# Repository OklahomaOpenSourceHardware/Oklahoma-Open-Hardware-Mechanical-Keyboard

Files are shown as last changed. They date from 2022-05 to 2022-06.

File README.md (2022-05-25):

# Oklahoma-Open-Hardware-Mechanical-Keyboard
Oklahoma themed open source hardware licensed keyboard from the Oklahoma community

## Layout

http://www.keyboard-layout-editor.com/#/gists/58d102278691380e818329089bf505ac

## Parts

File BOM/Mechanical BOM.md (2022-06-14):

| Version  | Reference  | Quantity  | Description  | Link  |
|---|---|---|---|---|
| Proto | S1 | 8 | Phillips Flat Head Screws: M3 x 0.5 mm Thread, 14 mm Long | https://www.mcmaster.com/91420A124/  |
| Proto | T1 | 4 | Tapered Heat-Set Inserts for Plastic Brass, M3 x 0.50 mm Thread Size, 3.800 mm Installed Length | https://www.mcmaster.com/94180A331/ |
| Proto | A1 | 1 | 5.4mm Acrylic (Open cut file) | https://sendcutsend.com/materials/acrylic/ |
| Proto | A2 | 1 | 4.5mm Acrylic (Close cut file) | https://sendcutsend.com/materials/acrylic/ |
| Proto | F1 | 1 | 1.6mm FR4 (Top Plate) | (link to gerber file) |
| Proto | F2 | 1 | 1.6mm FR4 (Keyboard PCB) | (link to gerber file) |
| Proto | F3 | 1 | 1.6mm FR4 (Bottom Plate) | (link to gerber file) |
| Proto | W1 | 1 | 9mm  Wedge Wood/Plastic | (link to 3D model file) |
| Proto | W2 | 1 | 8mm  Switch Cover Wood/Plastic | (link to 3D model file) |
| Proto | W3 | 1 | ~3mm  PCB Spacer TPU/Foam Plastic | (link to 3D model file) |

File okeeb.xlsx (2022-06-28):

Value | Reference(s) | Footprint
0.1u | C1, C2, C3, C4 | Capacitor_SMD:C_0805_2012Metric_Pad1.18x1.45mm_HandSolder
4.7u | C5 | Capacitor_SMD:C_0805_2012Metric_Pad1.18x1.45mm_HandSolder
22p | C6, C7 | Capacitor_SMD:C_0805_2012Metric_Pad1.18x1.45mm_HandSolder
1u | C8 | Capacitor_SMD:C_0805_2012Metric_Pad1.18x1.45mm_HandSolder
D | D0, D1, D2, D3, D4, D5, D6, D7, D8, D9, D10, D11, D12, D13, D14, D16, D17, D18, D19, D20, D21, D22, D23, D24, D25, D26, D27, D28, D29, D30, D31, D32, D33, D34, D35, D36, D37, D38, D39, D40, D41, D42, D43, D44, D45, D46, D47, D48, D49, D50, D51, D52, D53, D54, D55, D56, D57, D58, D59, D60, D61, D62, D63 | Diode_SMD:D_0805_2012Metric_Pad1.15x1.40mm_HandSolder
w_2 stabilizer | DRA1, DRA2, DRA5 | Mounting_Keyboard_Stabilizer:Stabilizer_Cherry_MX_2.00u
w_3 stabilizer | DRA3, DRA4 | Mounting_Keyboard_Stabilizer:Stabilizer_Cherry_MX_3.00u
MountingHole | H1, H2, H3, H4 | MountingHole:MountingHole_3.2mm_M3_DIN965
USB_B_Micro | J1 | Connector_USB:USB_Micro-B_Wuerth_629105150521_CircularHoles
Conn_02x03_Odd_Even | J2 | Connector_PinHeader_2.54mm:PinHeader_2x03_P2.54mm_Vertical
KEYSW | K0, K1, K2, K3, K4, K5, K6, K7, K8, K9, K10, K11, K12, K13, K14, K16, K17, K18, K19, K20, K21, K22, K23, K24, K25, K26, K27, K28, K29, K30, K31, K32, K33, K34, K35, K36, K37, K38, K39, K40, K41, K42, K43, K44, K45, K46, K47, K48, K49, K50, K51, K52, K53, K54, K55, K56, K57, K58, K59, K60, K61, K62, K63 | keyswitches:Kailh_socket_MX_p1ref
10k | R1, R4 | Resistor_SMD:R_0805_2012Metric_Pad1.20x1.40mm_HandSolder
22R | R2, R3 | Resistor_SMD:R_0805_2012Metric_Pad1.20x1.40mm_HandSolder
Reset_SW | SW1 | Button_Switch_SMD:SW_Push_1P1T_NO_6x6mm_H9.5mm
ATmega32U4-A | U1 | Package_QFP:TQFP-44_10x10mm_P0.8mm
Crystal | Y1 | Crystal:Crystal_SMD_5032-2Pin_5.0x3.2mm_HandSoldering

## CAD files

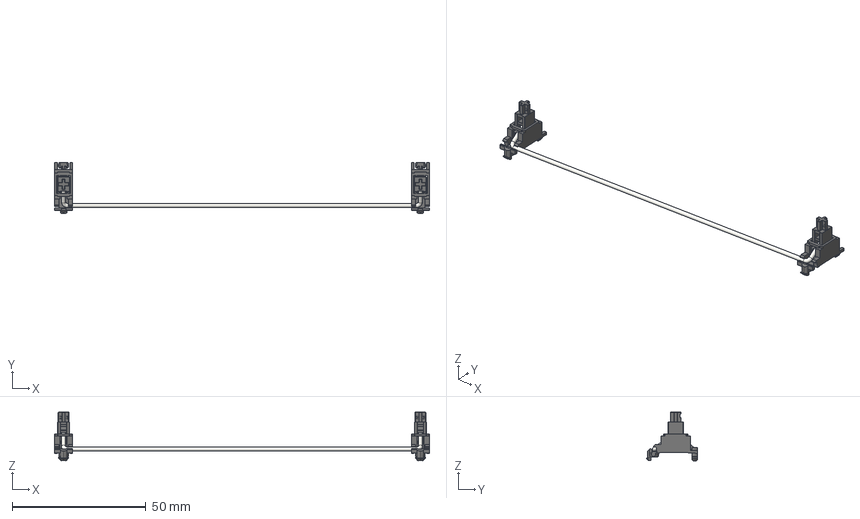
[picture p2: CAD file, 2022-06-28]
keyswitch-kicad-library-main/source_3d/Mounting_Keyboard_Stabilizer/Stabilizer_Cherry_MX_8u.FCStd
140.1 x 19.2 x 18.3 mm
Bar
Stabilizer_Key_
Stabilizer_Base_
Stabilizer_Key
Stabilizer_Base

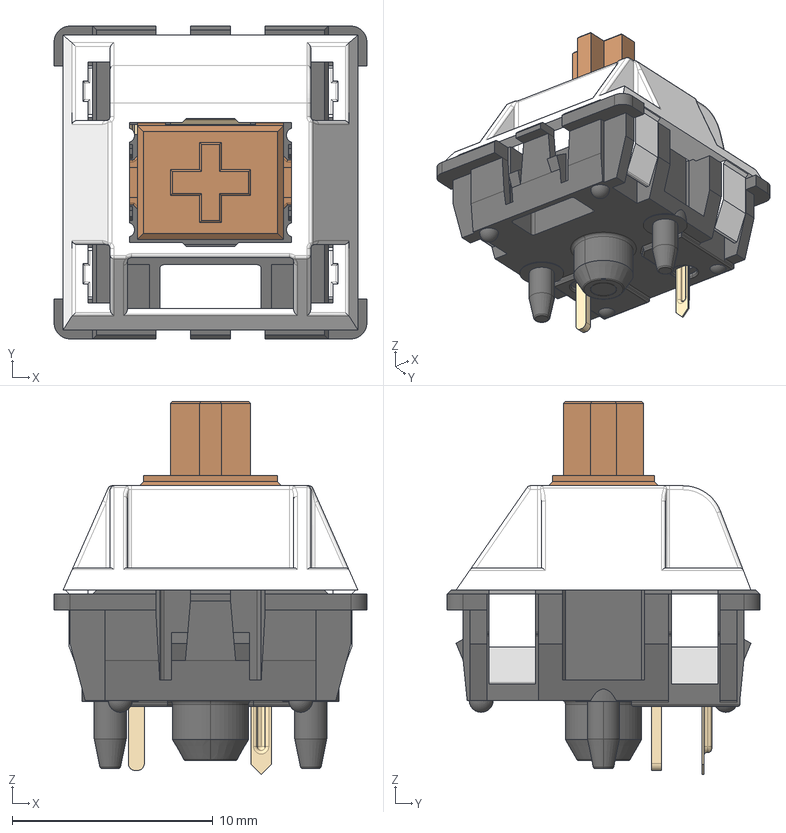
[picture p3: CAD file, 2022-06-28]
keyswitch-kicad-library-main/source_3d/Switch_Keyboard_Cherry_MX/SW_Cherry_MX_PCB.FCStd
15.6 x 15.6 x 18.6 mm
Lower_Housing
Upper_Housing
Stem
Pin_1
Pin_2
Spring
Clicker

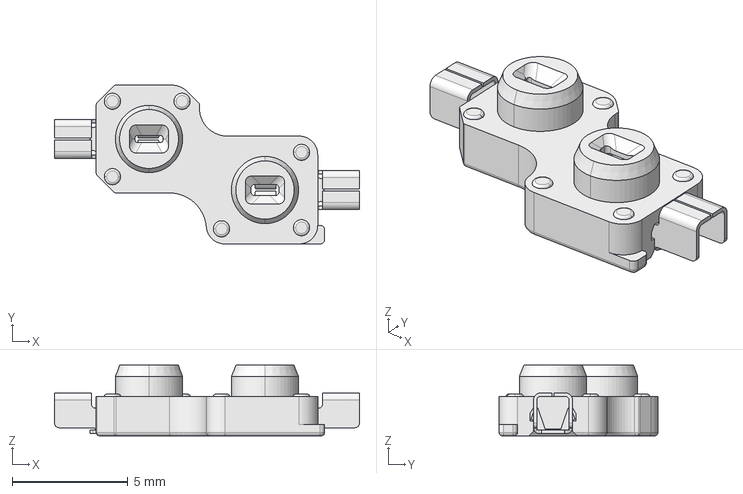
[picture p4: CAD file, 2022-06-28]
keyswitch-kicad-library-main/source_3d/Switch_Keyboard_Kailh/SW_Hotswap_Kailh_Choc_v1.FCStd
13.2 x 6.85 x 3.05 mm

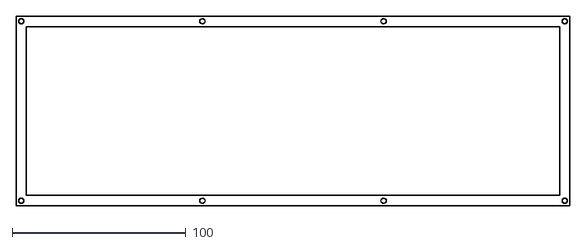
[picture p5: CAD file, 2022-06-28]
Mechanical/1d330ba3ae6bdd7f7d86c17163a86d3b664da0f7_closed.dxf
318.8 x 109.2

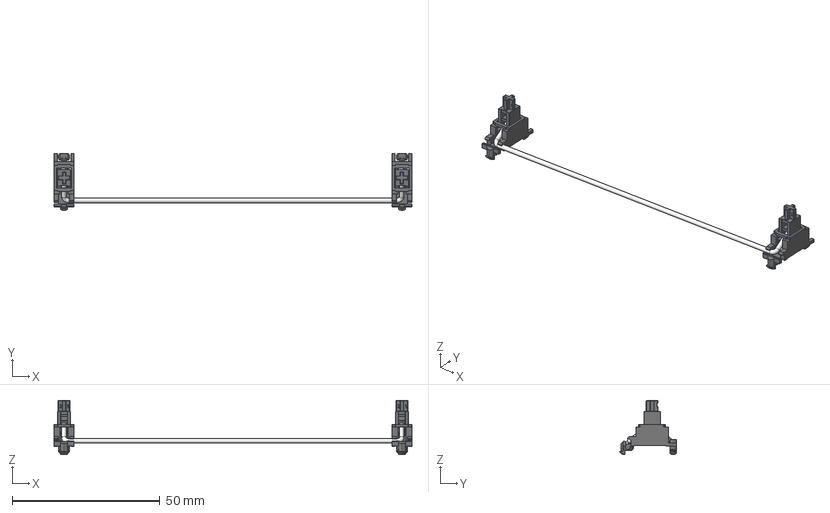
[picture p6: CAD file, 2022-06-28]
keyswitch-kicad-library-main/source_3d/Mounting_Keyboard_Stabilizer/Stabilizer_Cherry_MX_7u.FCStd
121.1 x 19.2 x 18.3 mm
Bar
Stabilizer_Key_
Stabilizer_Base_
Stabilizer_Key
Stabilizer_Base

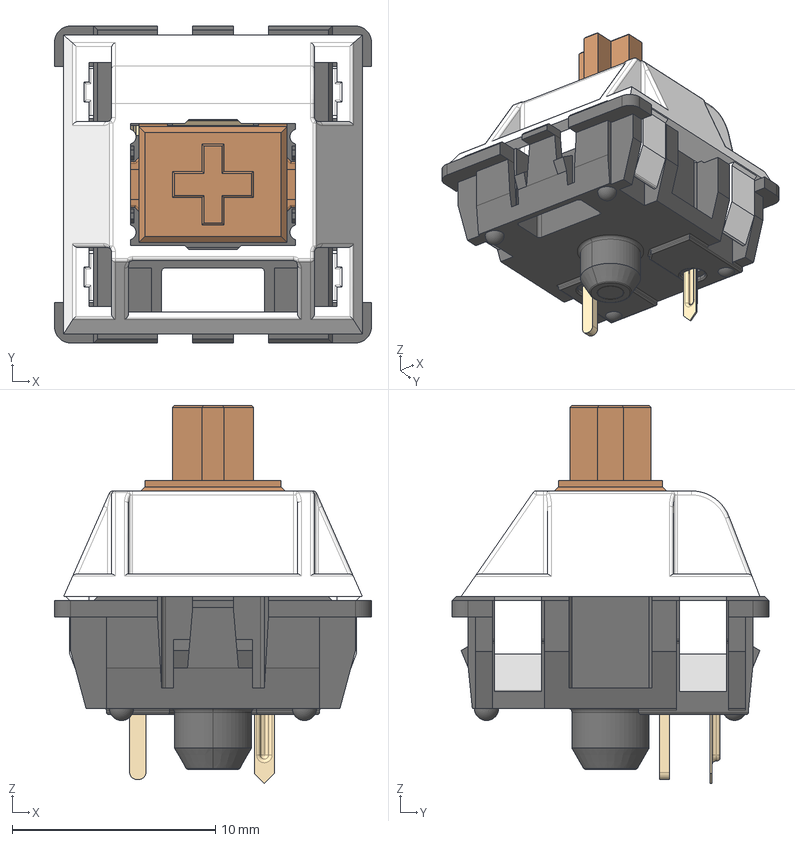
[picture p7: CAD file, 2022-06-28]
keyswitch-kicad-library-main/source_3d/Switch_Keyboard_Cherry_MX/SW_Cherry_MX_Plate.FCStd
15.6 x 15.6 x 18.6 mm
Lower_Housing
Upper_Housing
Stem
Pin_1
Pin_2
Spring
Clicker

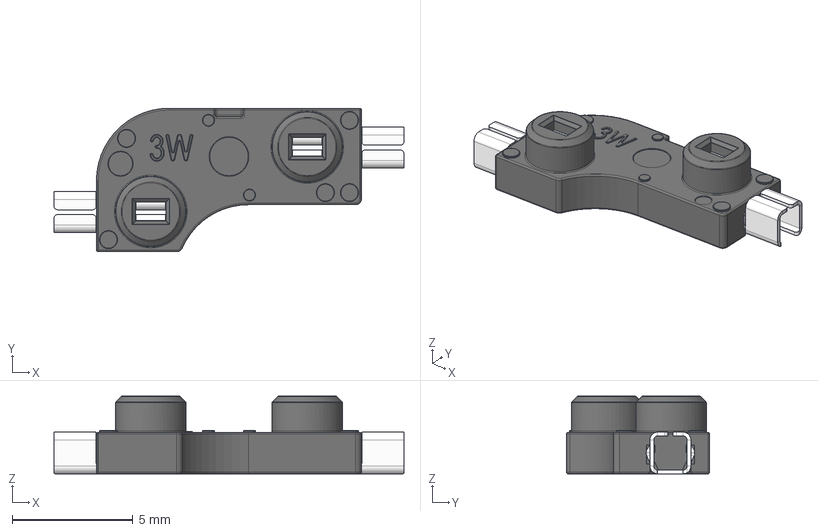
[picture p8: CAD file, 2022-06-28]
keyswitch-kicad-library-main/source_3d/Switch_Keyboard_Kailh/SW_Hotswap_Kailh.FCStd
14.5 x 5.95 x 3.22 mm
Pin_1
Pin_2
Plastic

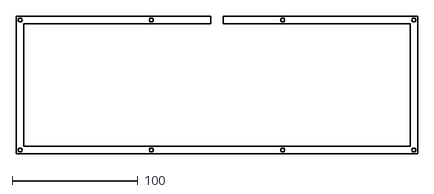
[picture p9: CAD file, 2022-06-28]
Mechanical/1d330ba3ae6bdd7f7d86c17163a86d3b664da0f7_open.dxf
318.8 x 109.2

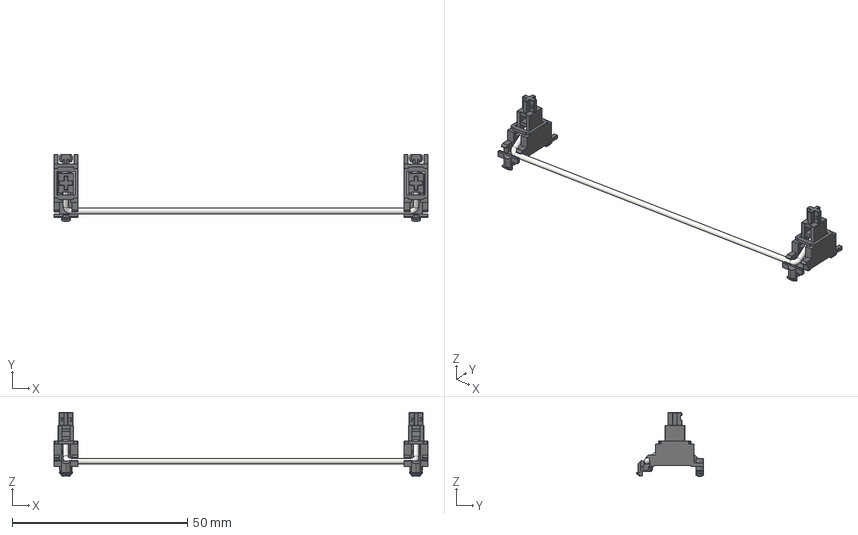
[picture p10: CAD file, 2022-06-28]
keyswitch-kicad-library-main/source_3d/Mounting_Keyboard_Stabilizer/Stabilizer_Cherry_MX_6.25u.FCStd
106.8 x 19.2 x 18.3 mm
Bar
Stabilizer_Key_
Stabilizer_Base_
Stabilizer_Key
Stabilizer_Base

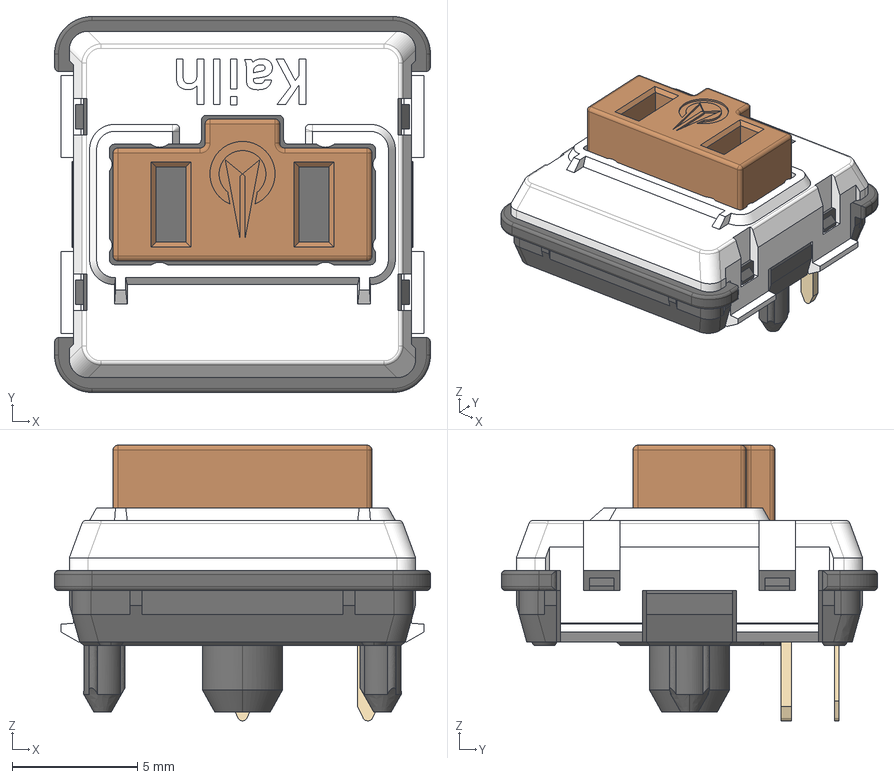
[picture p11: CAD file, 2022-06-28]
keyswitch-kicad-library-main/source_3d/Switch_Keyboard_Kailh/SW_Kailh_Choc_V1.FCStd
15.0 x 15.0 x 11.0 mm
Upper_Housing
Lower_Housing
Stem
Pin_2
Pin_1

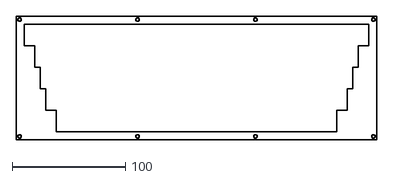
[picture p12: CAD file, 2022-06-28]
Mechanical/1d330ba3ae6bdd7f7d86c17163a86d3b664da0f7_top.dxf
318.8 x 109.2

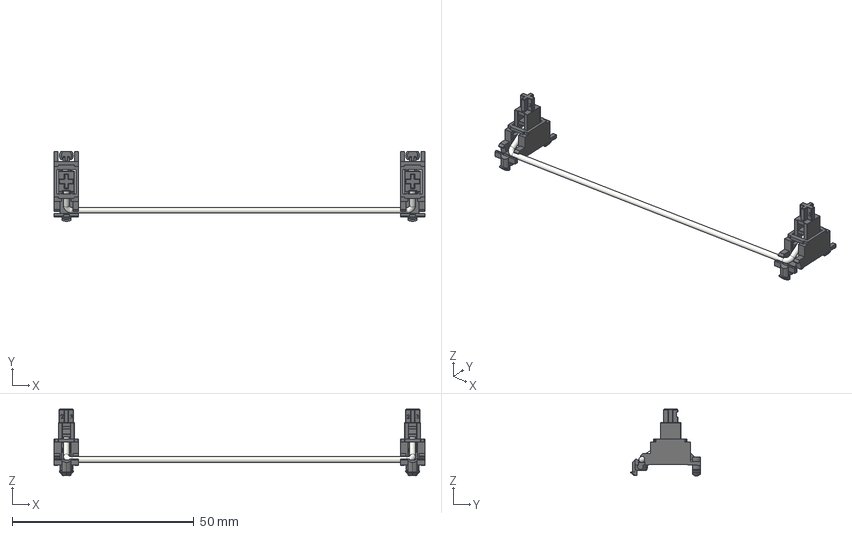
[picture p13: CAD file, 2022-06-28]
keyswitch-kicad-library-main/source_3d/Mounting_Keyboard_Stabilizer/Stabilizer_Cherry_MX_6u.FCStd
102.1 x 19.2 x 18.3 mm
Bar
Stabilizer_Key_
Stabilizer_Base_
Stabilizer_Key
Stabilizer_Base

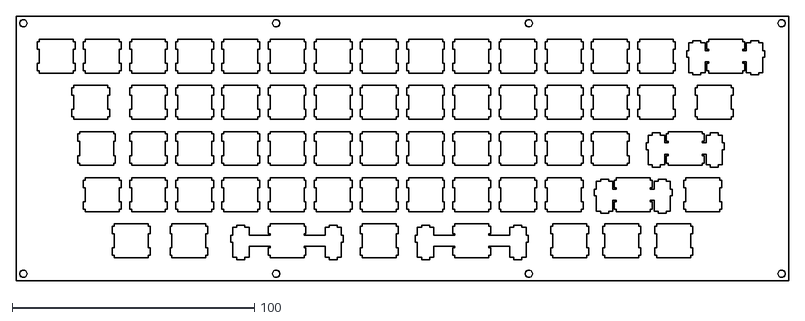
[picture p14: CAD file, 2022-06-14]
Mechanical/1d330ba3ae6bdd7f7d86c17163a86d3b664da0f7_switch.dxf
318.8 x 109.2

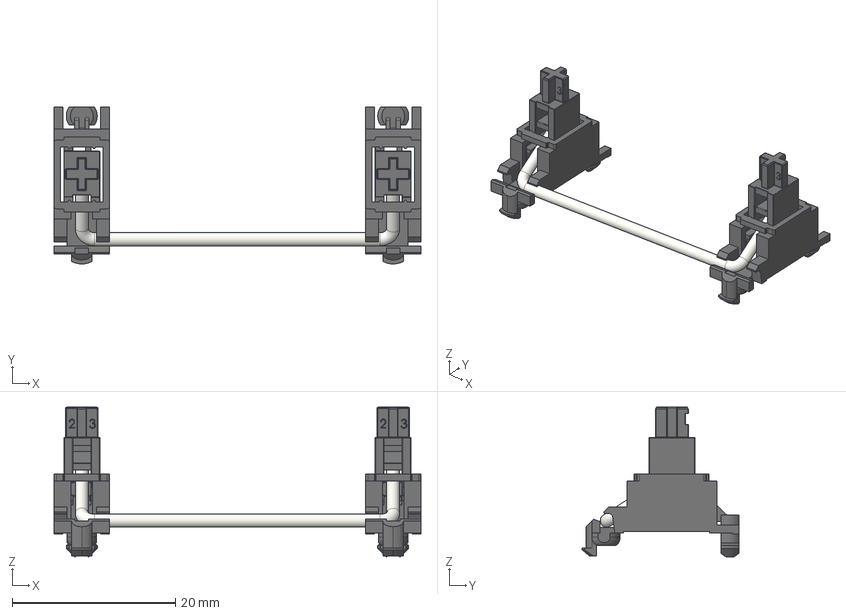
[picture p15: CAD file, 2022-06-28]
keyswitch-kicad-library-main/source_3d/Mounting_Keyboard_Stabilizer/Stabilizer_Cherry_MX_3u.FCStd
44.9 x 19.2 x 18.3 mm
Bar
Stabilizer_Key_
Stabilizer_Base_
Stabilizer_Key
Stabilizer_Base

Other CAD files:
Mechanical/1d330ba3ae6bdd7f7d86c17163a86d3b664da0f7_bottom.dxf
keyswitch-kicad-library-main/source_3d/Mounting_Keyboard_Stabilizer/Stabilizer_Cherry_MX_2u.FCStd

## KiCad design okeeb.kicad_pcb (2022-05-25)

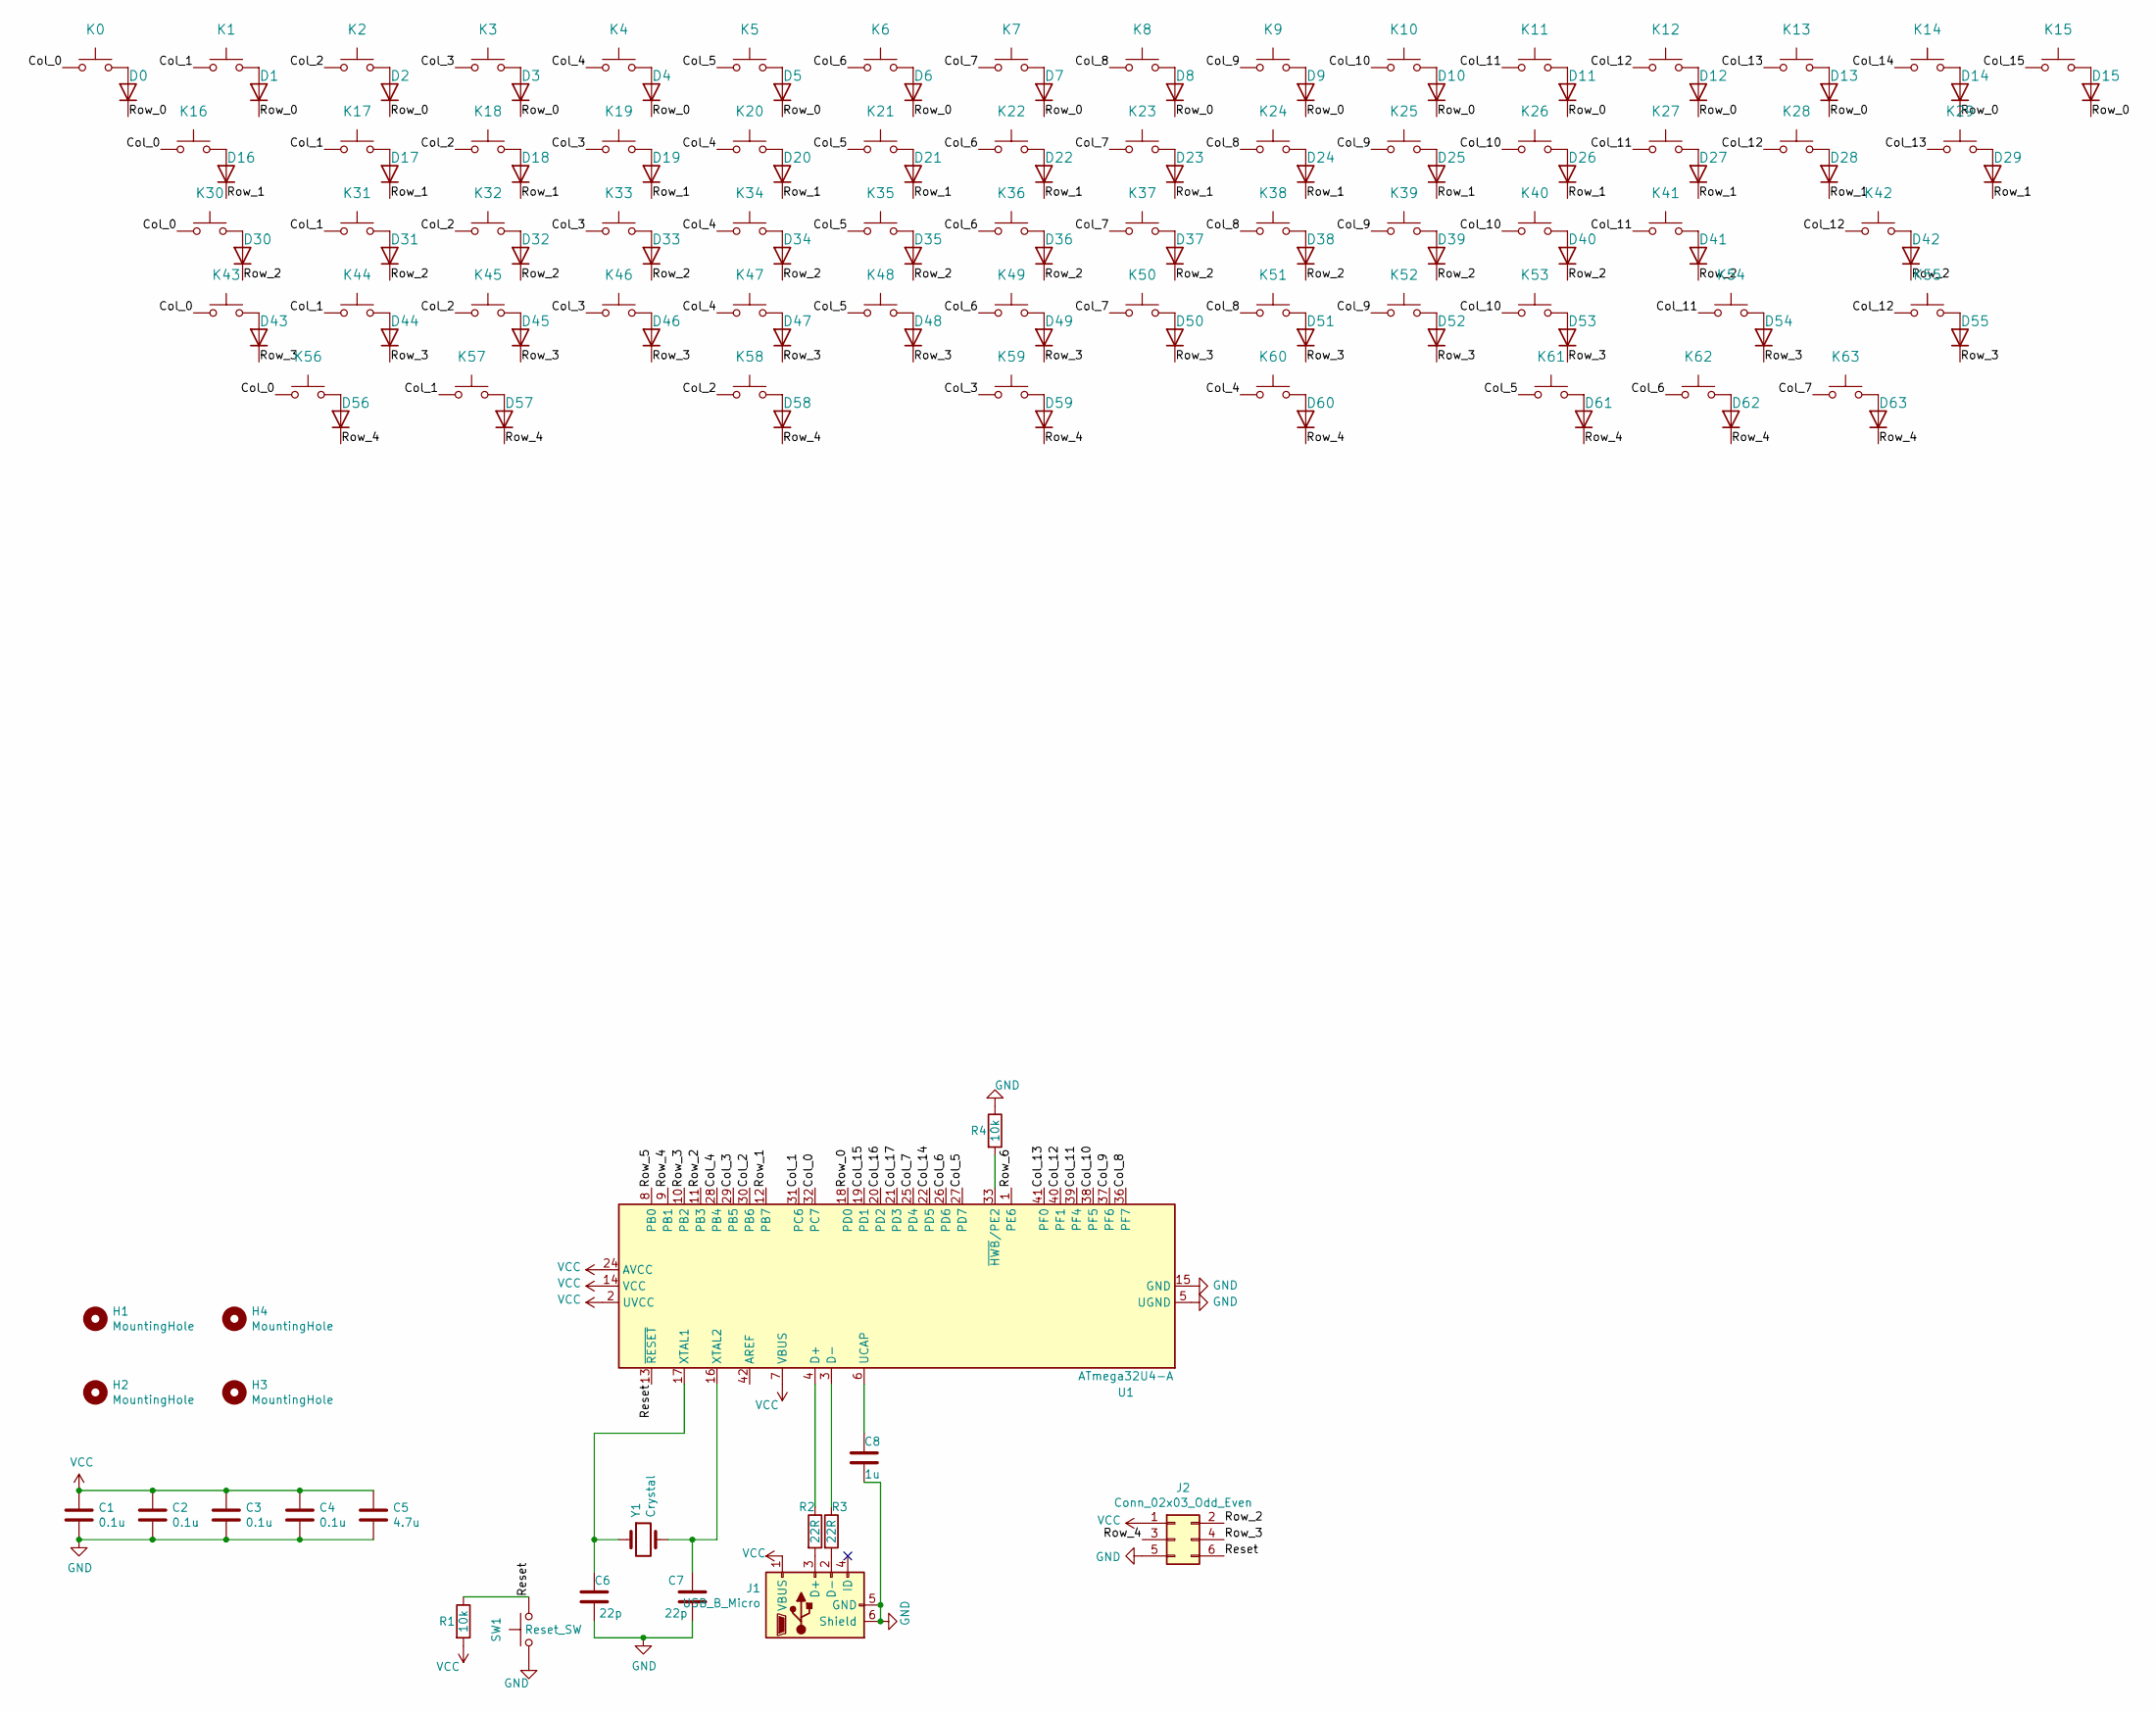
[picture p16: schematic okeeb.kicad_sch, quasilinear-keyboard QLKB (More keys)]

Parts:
C1, C2, C3, C4: 0.1u; C_0805_2012Metric_Pad1.15x1.40mm_HandSolder
C5: 4.7u; C_0805_2012Metric_Pad1.15x1.40mm_HandSolder
C6, C7: 22p; C_0805_2012Metric_Pad1.15x1.40mm_HandSolder
C8: 1u; C_0805_2012Metric_Pad1.15x1.40mm_HandSolder
D0, D1, D2, D3, D4, D5, D6, D7, D8, D9, D10, D11, D12, D13, D14, D15, D16, D17, D18, D19, D20, D21, D22, D23, D24, D25, D26, D27, D28, D29, D30, D31, D32, D33, D34, D35, D36, D37, D38, D39, D40, D41, D42, D43, D44, D45, D46, D47, D48, D49, D50, D51, D52, D53, D54, D55, D56, D57, D58, D59, D60, D61, D62, D63: D; D_0805_2012Metric_Pad1.15x1.40mm_HandSolder
H1, H2, H3, H4: MountingHole; MountingHole_3.2mm_M3_DIN965
J1: USB_B_Micro; USB_Micro-B_Wuerth_629105150521_CircularHoles
J2: Conn_02x03_Odd_Even; PinHeader_2x03_P2.54mm_Vertical
K0, K1, K2, K3, K4, K5, K6, K7, K8, K9, K10, K11, K12, K13, K14, K15, K17, K18, K19, K20, K21, K22, K23, K24, K25, K26, K27, K28, K31, K32, K33, K34, K35, K36, K37, K38, K39, K40, K41, K43, K44, K45, K46, K47, K48, K49, K50, K51, K52, K53, K55, K59, K62: KEYSW; SW_Cherry_MX_1.00u_PCB
K16, K29: KEYSW; SW_Cherry_MX_1.50u_PCB
K30, K56, K57, K61, K63: KEYSW; SW_Cherry_MX_1.25u_PCB
K42: KEYSW; SW_Cherry_MX_2.25u_PCB
K54: KEYSW; SW_Cherry_MX_2.00u_PCB
K58, K60: KEYSW; SW_Cherry_MX_2.75u_PCB
R1, R4: 10k; R_0805_2012Metric_Pad1.15x1.40mm_HandSolder
R2, R3: 22R; R_0805_2012Metric_Pad1.15x1.40mm_HandSolder
SW1: Reset_SW; SW_Push_1P1T_NO_6x6mm_H9.5mm
U1: ATmega32U4-A; TQFP-44_10x10mm_P0.8mm
Y1: Crystal; Crystal_SMD_5032-2Pin_5.0x3.2mm_HandSoldering

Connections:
/Col_0: K0.1, K16.1, K30.1, K43.1, K56.1, U1.32 (PC7)
/Col_1: K1.1, K17.1, K31.1, K44.1, K57.1, U1.31 (PC6)
/Col_2: K2.1, K18.1, K32.1, K45.1, K58.1, U1.30 (PB6)
/Col_3: K3.1, K19.1, K33.1, K46.1, K59.1, U1.29 (PB5)
/Col_4: K4.1, K20.1, K34.1, K47.1, K60.1, U1.28 (PB4)
/Col_5: K5.1, K21.1, K35.1, K48.1, K61.1, U1.27 (PD7)
/Col_6: K6.1, K22.1, K36.1, K49.1, K62.1, U1.26 (PD6)
/Col_7: K7.1, K23.1, K37.1, K50.1, K63.1, U1.25 (PD4)
/Col_8: K8.1, K24.1, K38.1, K51.1, U1.36 (PF7)
/Col_9: K9.1, K25.1, K39.1, K52.1, U1.37 (PF6)
/Col_10: K10.1, K26.1, K40.1, K53.1, U1.38 (PF5)
/Col_11: K11.1, K27.1, K41.1, K54.1, U1.39 (PF4)
/Col_12: K12.1, K28.1, K42.1, K55.1, U1.40 (PF1)
/Col_13: K13.1, K29.1, U1.41 (PF0)
/Col_14: K14.1, U1.22 (PD5)
/Col_15: K15.1, U1.19 (PD1)
/Col_16: U1.20 (PD2)
/Col_17: U1.21 (PD3)
/Row_0: D0.1 (K), D1.1 (K), D2.1 (K), D3.1 (K), D4.1 (K), D5.1 (K), D6.1 (K), D7.1 (K), D8.1 (K), D9.1 (K), D10.1 (K), D11.1 (K), D12.1 (K), D13.1 (K), D14.1 (K), D15.1 (K), U1.18 (PD0)
/Row_1: D16.1 (K), D17.1 (K), D18.1 (K), D19.1 (K), D20.1 (K), D21.1 (K), D22.1 (K), D23.1 (K), D24.1 (K), D25.1 (K), D26.1 (K), D27.1 (K), D28.1 (K), D29.1 (K), U1.12 (PB7)
/Row_2: D30.1 (K), D31.1 (K), D32.1 (K), D33.1 (K), D34.1 (K), D35.1 (K), D36.1 (K), D37.1 (K), D38.1 (K), D39.1 (K), D40.1 (K), D41.1 (K), D42.1 (K), J2.2, U1.11 (PB3)
/Row_3: D43.1 (K), D44.1 (K), D45.1 (K), D46.1 (K), D47.1 (K), D48.1 (K), D49.1 (K), D50.1 (K), D51.1 (K), D52.1 (K), D53.1 (K), D54.1 (K), D55.1 (K), J2.4, U1.10 (PB2)
/Row_4: D56.1 (K), D57.1 (K), D58.1 (K), D59.1 (K), D60.1 (K), D61.1 (K), D62.1 (K), D63.1 (K), J2.3, U1.9 (PB1)
/Row_5: U1.8 (PB0)
/Row_6: U1.1 (PE6)
GND: C1.2, C2.2, C3.2, C4.2, C5.2, C6.2, C7.2, C8.2, J1.5 (GND), J1.6 (Shield), J2.5, R4.1, SW1.1, U1.5 (UGND), U1.15 (GND), U1.23 (GND), U1.35 (GND), U1.43 (GND)
unnamed: C6.1, U1.17 (XTAL1), Y1.1
unnamed: C7.1, U1.16 (XTAL2), Y1.2
unnamed: C8.1, U1.6 (UCAP)
unnamed: D0.2 (A), K0.2
unnamed: D1.2 (A), K1.2
unnamed: D2.2 (A), K2.2
unnamed: D3.2 (A), K3.2
unnamed: D4.2 (A), K4.2
unnamed: D5.2 (A), K5.2
unnamed: D6.2 (A), K6.2
unnamed: D7.2 (A), K7.2
unnamed: D8.2 (A), K8.2
unnamed: D9.2 (A), K9.2
unnamed: D10.2 (A), K10.2
unnamed: D11.2 (A), K11.2
unnamed: D12.2 (A), K12.2
unnamed: D13.2 (A), K13.2
unnamed: D14.2 (A), K14.2
unnamed: D15.2 (A), K15.2
unnamed: D16.2 (A), K16.2
unnamed: D17.2 (A), K17.2
unnamed: D18.2 (A), K18.2
unnamed: D19.2 (A), K19.2
unnamed: D20.2 (A), K20.2
unnamed: D21.2 (A), K21.2
unnamed: D22.2 (A), K22.2
unnamed: D23.2 (A), K23.2
unnamed: D24.2 (A), K24.2
unnamed: D25.2 (A), K25.2
unnamed: D26.2 (A), K26.2
unnamed: D27.2 (A), K27.2
unnamed: D28.2 (A), K28.2
unnamed: D29.2 (A), K29.2
unnamed: D30.2 (A), K30.2
unnamed: D31.2 (A), K31.2
unnamed: D32.2 (A), K32.2
unnamed: D33.2 (A), K33.2
unnamed: D34.2 (A), K34.2
unnamed: D35.2 (A), K35.2
unnamed: D36.2 (A), K36.2
unnamed: D37.2 (A), K37.2
unnamed: D38.2 (A), K38.2
unnamed: D39.2 (A), K39.2
unnamed: D40.2 (A), K40.2
unnamed: D41.2 (A), K41.2
unnamed: D42.2 (A), K42.2
unnamed: D43.2 (A), K43.2
unnamed: D44.2 (A), K44.2
unnamed: D45.2 (A), K45.2
unnamed: D46.2 (A), K46.2
unnamed: D47.2 (A), K47.2
unnamed: D48.2 (A), K48.2
unnamed: D49.2 (A), K49.2
unnamed: D50.2 (A), K50.2
unnamed: D51.2 (A), K51.2
unnamed: D52.2 (A), K52.2
unnamed: D53.2 (A), K53.2
unnamed: D54.2 (A), K54.2
unnamed: D55.2 (A), K55.2
unnamed: D56.2 (A), K56.2
unnamed: D57.2 (A), K57.2
unnamed: D58.2 (A), K58.2
unnamed: D59.2 (A), K59.2
unnamed: D60.2 (A), K60.2
unnamed: D61.2 (A), K61.2
unnamed: D62.2 (A), K62.2
unnamed: D63.2 (A), K63.2
unnamed: R2.1, U1.4 (D+)
unnamed: R3.1, U1.3 (D-)
unnamed: R4.2, U1.33 (~HWB/PE2)
VCC: C1.1, C2.1, C3.1, C4.1, C5.1, J1.1 (VBUS), J2.1, R1.2, U1.2 (UVCC), U1.7 (VBUS), U1.14 (VCC), U1.24 (AVCC), U1.34 (VCC), U1.44 (AVCC)

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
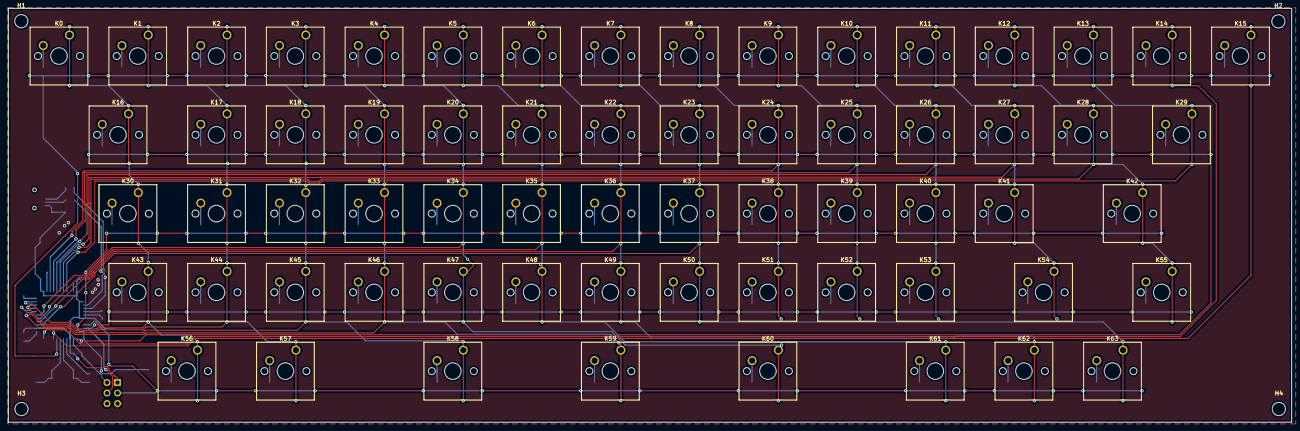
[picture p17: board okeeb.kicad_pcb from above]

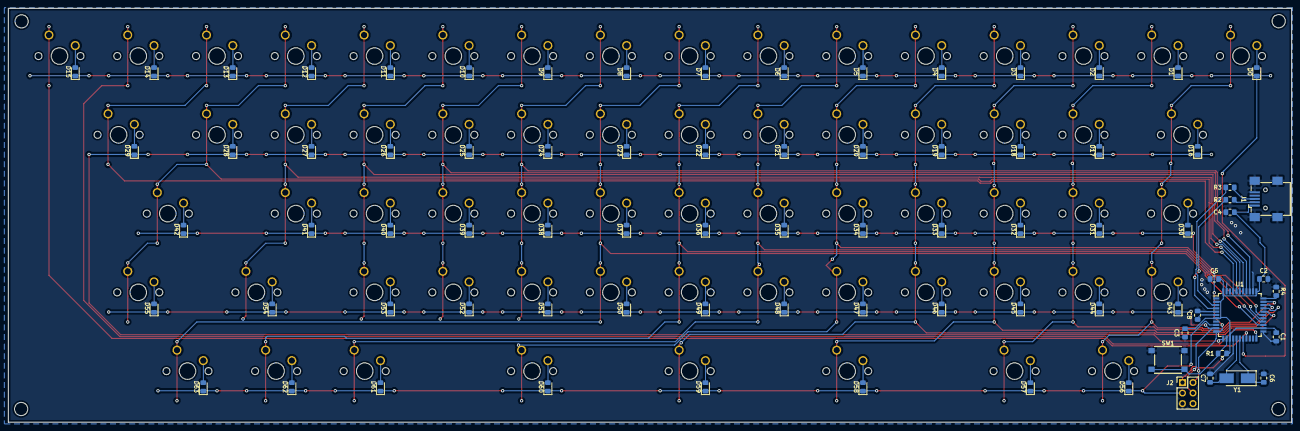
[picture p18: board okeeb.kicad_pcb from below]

Board: 2 copper layers, 310.4 x 100.1 mm, 149 parts (81 on the bottom side), 96 nets.

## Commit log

2022-05-25 Initial commit
    Used https://github.com/jeroen94704/klepcbgen to generate initial layout
    Based on this design http://www.keyboard-layout-editor.com/#/gists/58d102278691380e818329089bf505ac
    [okeeb.kicad_pcb, okeeb.kicad_sch, okeeb.sch]
2022-06-08 added kaailh sockets Signed-off-by: lokimetasmith <lokimail@gmail.com>
    [okeeb.kicad_sch, okeeb.sch]
2022-06-14 added mechanical drawings first draft, and list of parts in BOM for mechanical components
    [1d330ba3ae6bdd7f7d86c17163a86d3b664da0f7_bottom.dxf, 1d330ba3ae6bdd7f7d86c17163a86d3b664da0f7_switch.dxf]
2022-06-16 adding in 3D models and changed key 15 so it only has one key as opposed to two
    [okeeb.kicad_sch]
2022-06-29 converting it to ESP32-s3, added LED's, USB-C, IO expanders, and switching power supply
    [okeeb.kicad_sch]
2022-06-29 initial schematic capture
    [okeeb.kicad_sch]
2022-07-09 updated libraries, lots of minor fixes
    [okeeb.kicad_sch]

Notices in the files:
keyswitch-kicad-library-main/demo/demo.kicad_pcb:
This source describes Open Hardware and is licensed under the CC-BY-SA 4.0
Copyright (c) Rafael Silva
